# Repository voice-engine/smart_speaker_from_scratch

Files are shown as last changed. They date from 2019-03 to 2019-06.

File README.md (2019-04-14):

Smart Speaker from Scratch
==========================



The project is about to make an affordable, open source smart speaker. It should be able to run Amazon Alexa, Google Assistant, MyCroft, Home Assistant, Mopidy and etc.

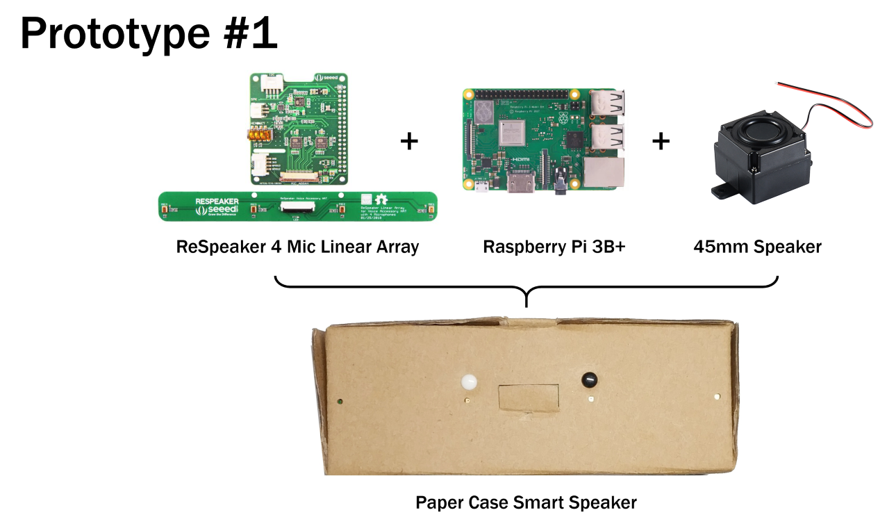
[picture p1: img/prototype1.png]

See the detail at [hardware/prototype-1](/hardware/prototype-1)

### To Do
- Hardware
  - [x] [prototype #1 - Rasbperry Pi + ReSpeaker 4 Mic Linear Array + 45mm Speaker](/hardware/prototype_1)
  - [ ] prototype #2 (on-going)
  - [ ] ...

- Software
  - [ ] AEC (Acoustic Echo Cancellation), See [ec](https://github.com/voice-engine/ec)
  - [ ] ...

- Design
  - [x] prototype #1 - paper case
  - [ ] prototype #2 - wood case, made with [Boxes](https://github.com/florianfesti/boxes)
  - [ ] ...

- Document
  - [x] [Record & Play Audio on Linux](https://github.com/voice-engine/make-a-smart-speaker/issues/5)
  - [ ] Steps to make prototype #1
  - [ ] Introduce how AEC works
  - [ ] ...

### Why

[中文](https://zhuanlan.zhihu.com/p/58690069)

Why should we make an open source smart speaker when there are so many smart speakers on the market? Because these smart speakers are designed from vendors' perspective, not from users' perspective. These smart speakers have two issues:

1. privacy - these speakers are always-listening black boxes which scare lots of people
2. functionality - these speakers can be more powerful, but are limited by the vendors

One best way to eliminate privacy concerns is open source.

Most of smart speakers have very powerful ARM processors. Some even run Android OS just like an Android phone.  The smart speakers only is limited to run only one app, but they have the ability to run thousands of applications.

I want an open source smart speaker which can run Amazon Alexa and Google Assistant at the same time, and also is able to run Home Assistant, Mopidy, Snapcast, Nextcloud and etc.
Maybe you want one too. You can this project on Github or [hackaday.io](https://hackaday.io/project/164221-smart-speaker-from-scratch)

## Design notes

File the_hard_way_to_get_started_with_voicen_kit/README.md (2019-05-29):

The Hard Way To Get Started with VOICEN Kit
===========================================

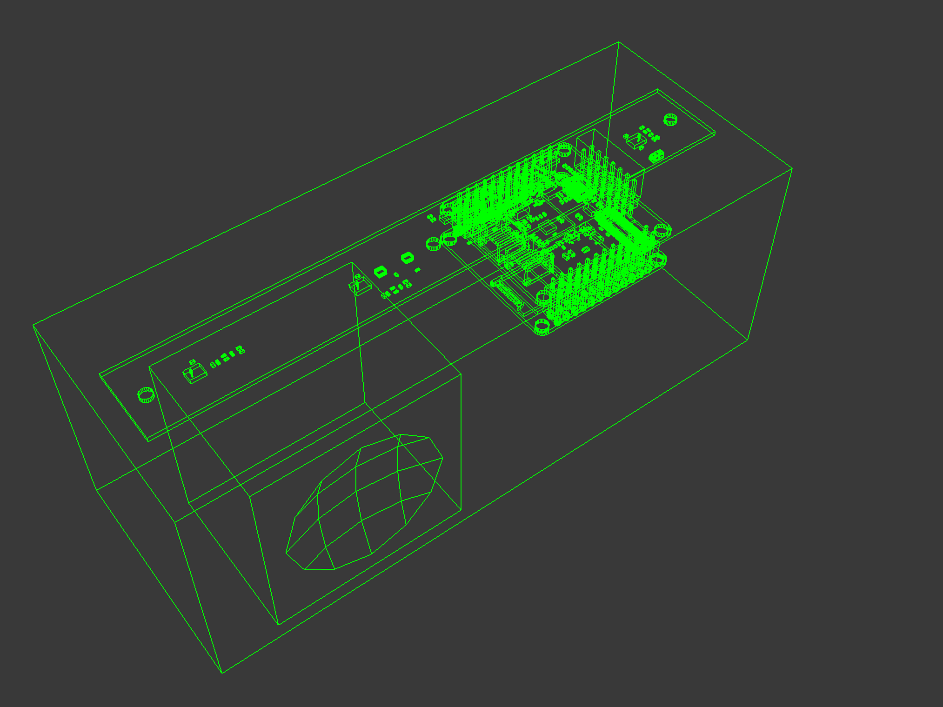
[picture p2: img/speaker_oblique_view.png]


## Hardware
+ VOICEN Kit (Nanopi Neo Air, VOICEN Linear 4 Mic Array, Nano AMP)
+ A SD card

## Setup
1. Download [Armbian for Nanopi Neo Air](https://www.armbian.com/nanopi-neo-air/)
2. Use [Rufus (very tiny but only for windows)](https://rufus.ie/) or [Ether](https://www.balena.io/etcher/) to write Armbian to a SD card.
3. Boot Nanopi Neo Air from the SD card, and then login it via USB virtual serial console. The default user is `root`, its password is `1234`. When you first login it, you will be ask to change the password and create a new user.
4. Use `nmtui` to connect to a WiFi.
5. Install [a customized linux kernel](https://github.com/voice-engine/packages/tree/master/pool/main/l/linux-4.19.25-sunxi) which contains the driver of the VOICEN Linear 4 Mic Array.

## IO Access
[Read/Write IO to control LEDs and to detect touch event ot the touch button.](GPIO)

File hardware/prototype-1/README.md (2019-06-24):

Prototype #1
============

[中文版](zh.md)

To make an open source smart speaker.

### Hardware



The hardware includes:

+ Raspberry Pi 3B
+ A micro SD card
+ ReSpeaker 4 Mic Linear Array
+ 45mm Speaker
+ Laser-Cut Paper Case
+ 2 Nylon Rivets (R3045), the diameter of mounting holes is 3mm (ф3). Screws also work, while rivets are easier to use.

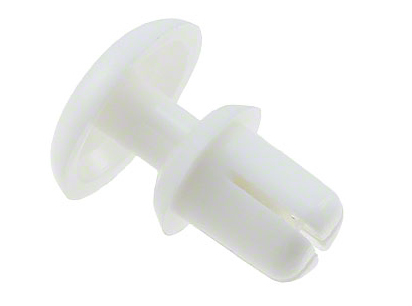
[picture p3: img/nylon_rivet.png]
  

Raspberry Pi and ReSpeaker 4 Mic Linear Array can be found at Seeed Studio, and we get the 45mm speaker and nylon rivets from Alibaba or Taobao.

### Software
+ [Raspbian for ReSpeaker](https://v2.fangcloud.com/share/7395fd138a1cab496fd4792fe5?folder_id=188000207913&lang=en)
+ [Etcher](https://www.balena.io/etcher/) or [Rufus (only for Windows)](https://rufus.akeo.ie/)
+ [VNC Viewer](https://www.realvnc.com/en/connect/download/viewer/chrome/)
+ A SSH client such as MobaXterm or Putty

### Steps
1. Download [a customized Pi image - 2018-08-06-raspbian-for-respeaker.zip](https://v2.fangcloud.com/share/7395fd138a1cab496fd4792fe5?folder_id=188000207913&lang=en)，
   which includes the driver for ReSpeaker 4 Mic Linear Array and some pre-installed packages. Do not use the lite version as we need the desktop enviroment to use a web browser.

2. We can write the image to a micro SD card with [Rufus](https://rufus.akeo.ie/) (very tiny but only for windows) or [Etcher](https://www.balena.io/etcher/).

3. (Optional) Use your computer or your phone to setup a hotspot.

4. Enable SSH and setup WiFi before the first boot of the Pi.

   Add a file named `ssh` to the boot partition of the SD card, which enables SSH, and then create a file named `wpa_supplicant.conf` with the following content (replace `WiFi SSID` and `WiFi Password` with yours):
   
   ```
   country=GB
   ctrl_interface=DIR=/var/run/wpa_supplicant GROUP=netdev
   update_config=1
   network={
	    ssid="WiFi SSID"
	    psk="WiFi Password"
   }
   ```
   
5. Boot your Pi with the SD card，find out its IP address and ssh to it (user:pi, password: raspberry).

   For Windows, use a SSH client such as [MobaXterm](https://mobaxterm.mobatek.net/) or [putty](https://www.chiark.greenend.org.uk/~sgtatham/putty/latest.html). For Linux or macOS, run `ssh` command in a terminal.

6. Enable the VNC server.

   In the SSH terminal, run `sudo raspi-config`, navigate to menus `Interfacing Options >> VNC` and enable the VNC server.

7. Use a VNC viewer to connect to the Pi's remote desktop.

8. Run some test commands:

   ```
   arecord -l                               # list capture devices
   arecord -f dat -d 6 -V mono audio.wav    # record an audio
   aplay -v audio.wav                       # play the audio
   python ~/respeaker/4mic_linear/aec_ns_kws.py   # detect keyword "snowboy", use ctrl + c to exit
   ```

   The output should be:

   ```
   pi@raspberrypi:~ $ arecord -l
   **** List of CAPTURE Hardware Devices ****
   card 1: seeed8micvoicec [seeed-8mic-voicecard], device 0: bcm2835-i2s-ac10x-codec0 ac10x-codec0-0 []
     Subdevices: 1/1
     Subdevice #0: subdevice #0
   pi@raspberrypi:~ $ arecord -f dat -d 6 -V mono audio.wav
   Recording WAVE 'audio.wav' : Signed 16 bit Little Endian, Rate 48000 Hz, Stereo
   ##+                                                | 02%
   pi@raspberrypi:~ $ aplay audio.wav
   Playing WAVE 'audio.wav' : Signed 16 bit Little Endian, Rate 48000 Hz, Stereo
   aplay: xrun:1624: read/write error, state = RUNNING
   pi@raspberrypi:~ $ aplay -v audio.wav
   ...
   pi@raspberrypi:~ $ aplay -v audio.wav
   pi@raspberrypi:~ $ python ~/respeaker/4mic_linear/aec_ns_kws.py
   ['arecord', '-t', 'raw', '-f', 'S16_LE', '-c', '8', '-r', '16000', '-D', 'default', '-q']
   detected 1
   detected 1
   ^Cquit
   ```

9. At the remote desktop window, setup Amazon Alexa Voice Service

   1. the default web browser has some compatible issues, so we need to replace it. open the Chromium web browser and set it as the default web
   2. run `alexa-auth`
   3. open http://127.0.0.1:3000 in the Chromium
   4. click `amazon alexa` and login alexa voice service with your amazon account

10. Run Alexa as a voice assistant

    ```
    cd
    wget https://github.com/voice-engine/smart_speaker_from_scratch/raw/master/hardware/prototype-1/alexa.py
    python alexa.py
    ```

11. Make the python script autorun

    ```
    wget https://github.com/voice-engine/smart_speaker_from_scratch/raw/master/hardware/prototype-1/alexa.service
    sudo cp alexa.service /etc/systemd/system
    sudo systemctl enable alexa.service
    sudo systemctl start alexa.service
    ```

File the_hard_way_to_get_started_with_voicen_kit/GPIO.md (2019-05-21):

GPIO
====

## IO Used By VOICEN Kit

| name | number  | usage |
|---|---|---|
| PA2 | 2 | AMP_PWR_EN |
| PA3 | 3 | AMP_MUTE |
| PC0 | 64 | BLUE LED |
| PC1 | 65 | GREEN LED |
| PC2 | 66 | YELLOW LED |
| PC3 | 67 | RED LED |
| PG11 | 203 | TOUCH BUTTON |

from name to number: 

`n(PC3) = ('C' - 'A') * 32 + 3 = 2 * 32 + 3 = 67`

## 3 ways to access IO
1. sysfs

2. gpiod

   ```
   sudo apt install -y gpiod
   sudo gpioset 0 65=0  # turn on green LED
   sudo gpiomon 0 203   # detect touch event 
   ```

3. direct memory (IO registers)

   ```
   sudo apt install -y sunxi-tools
   sudo sunxi-pio -m PC1=1  # turn on green LED
   ```

   ## Reference
   1. https://github.com/brgl/libgpiod
   2. https://github.com/linux-sunxi/sunxi-tools

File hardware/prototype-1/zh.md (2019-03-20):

原型 #1
=======



### 硬件
所用到的硬件包括:

+ 树莓派 3B 或 3B+
+ ReSpeaker 4 Mic Linear Array
+ 45mm 带音腔的喇叭
+ 激光切割的纸壳 （后面尝试不借助激光切割机 DIY 纸壳）
+ 2个尼龙铆钉 (R3035 或 R3045)，见下图，定位孔是ф3的，用螺丝螺母也可以，但尼龙铆钉使用起来更方便

  

树莓派、ReSpeaker 4 Mic Linear Array、喇叭、铆钉都可以在淘宝上买到，激光切割的纸壳可以在当地的创客空间里制作，很多创客空间都激光切割机、3D打印机。在深圳的话，可以去柴火创客空间，里面有各种各样的工具。

### 设计一个纸壳
激光切割纸壳需要一份CAD设计图，CAD倒是在大学的《机械工程制图》课中学过，已经好几个年头没有用过了，好在设计一个简单纸壳只需要画线、画圆即可，就是数字化尺规作图。
商业的CAD软件都很贵，但对于设计纸壳这个任务，用开源的[LibreCAD](https://librecad.org/)就可以搞定。

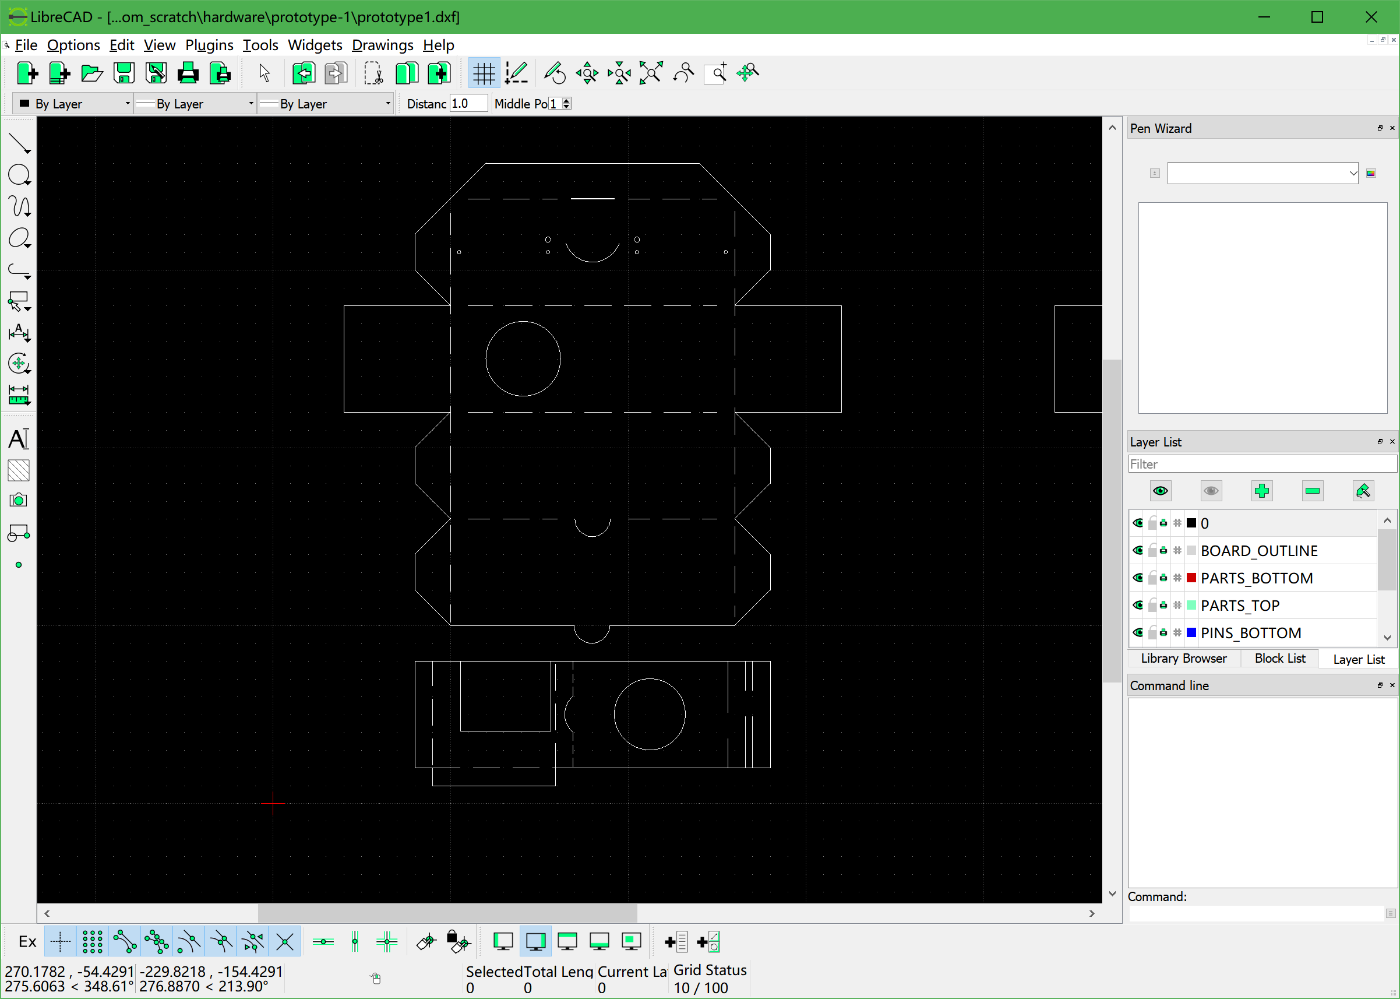
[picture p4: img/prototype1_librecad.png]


如果从来没有接触过CAD制图，上手CAD有一定的门槛，可以Python设计CAD图纸，这里用到[Manfred Moitzi写的一个很好用的Python库ezdxf](https://github.com/mozman/ezdxf)，我们把纸壳的尺寸算清楚，就可以在Python里面画线、画圆了。
用Python设计一些有规律的结构可能比用CAD更快速，比如说设计阵列喇叭孔。

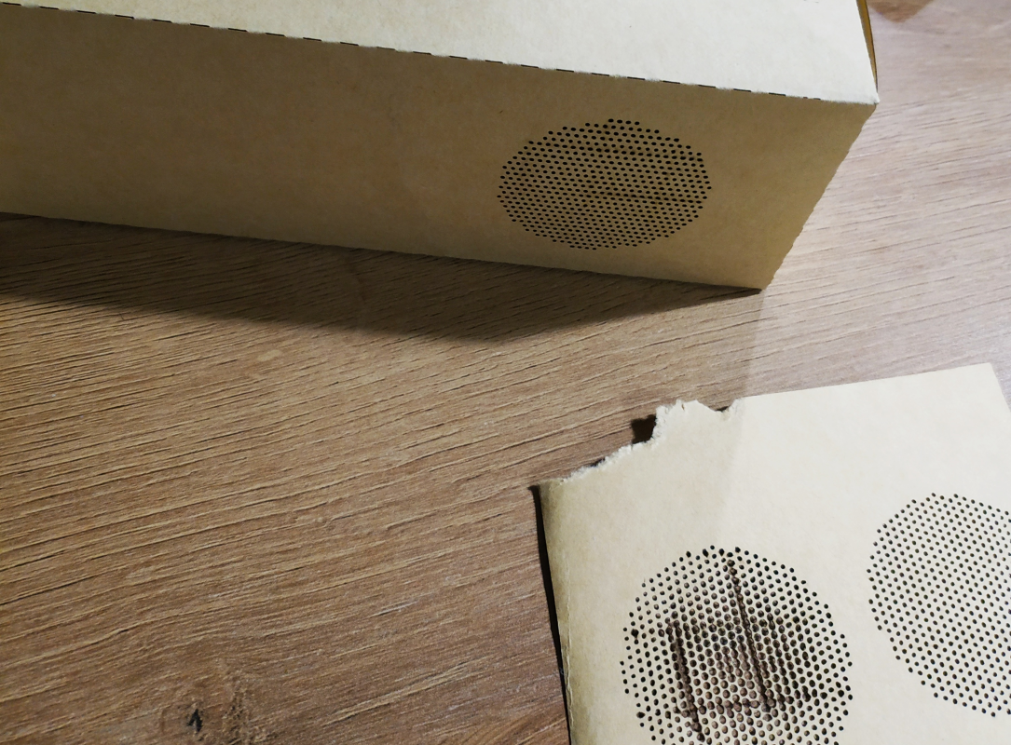
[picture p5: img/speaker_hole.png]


用Python代码设计这样的：

```python
import ezdxf

dwg = ezdxf.new('R2007')
msp = dwg.modelspace()
d = 40.
n = int(40 / 1.5)

delta = d / n

start = (100, 100)

msp.add_circle(start, 20)

for x in range(-n, n):
    for y in range(-n, n):
        if y & 1:
            offset = 0.5
        else:
            offset = 0
        rx = ((x + offset)**2 + y**2)**0.5
        if rx <= (n/2 + 0.1):
            r = 0.35 # (0.25 * delta * (n/2 - rx) / (n/2) + 0.15 * delta)
            msp.add_circle((start[0] + (x + offset) * delta, start[1] + y * delta), r)

dwg.saveas('speaker_hole.dxf')
```
这段代码输出的图形是：

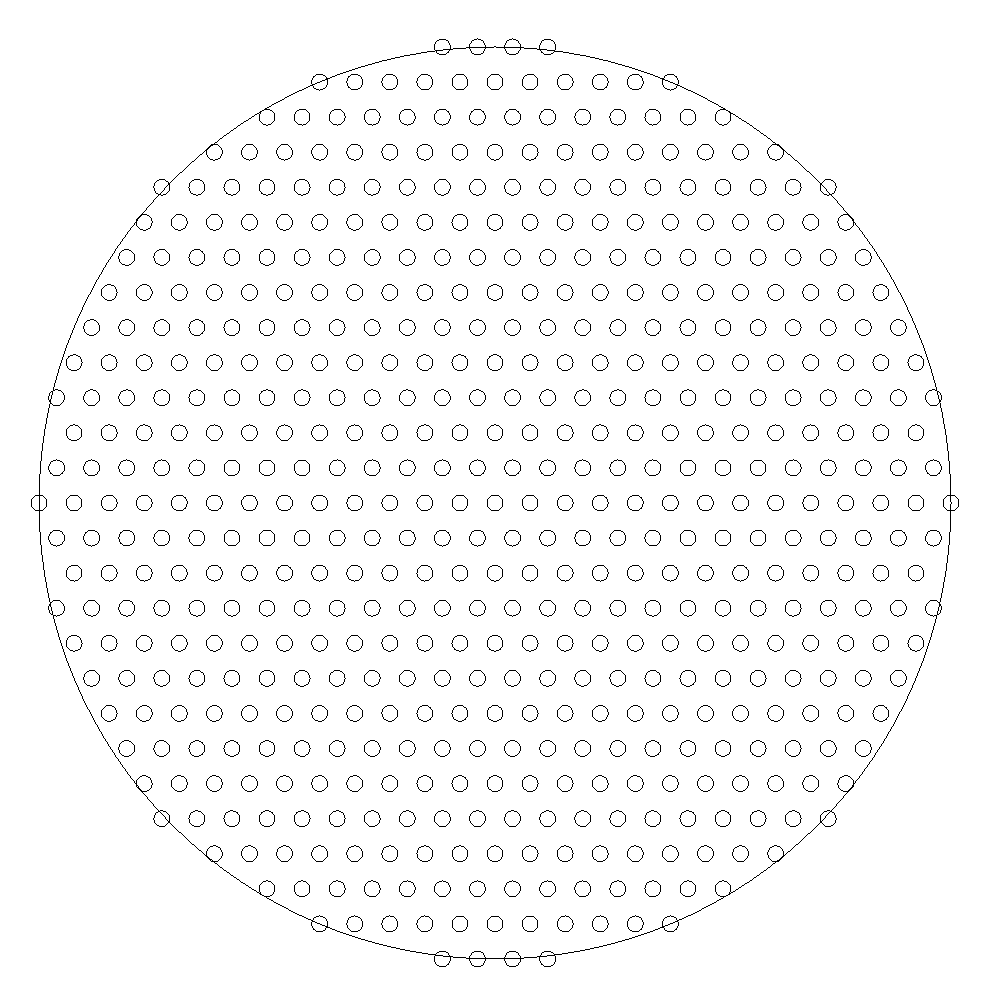
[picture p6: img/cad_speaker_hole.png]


可以将CAD和Python代码结合，进行更复杂的设计。

### 软件
实现语音交互智能音箱的功能，最简单的方法是用各大厂商提供的语音助手服务，Amazon、Google、百度都提供了多种编程语言SDK的支持，百度甚至推出兼容Amazon语音服务的API；像更深层次的折腾，可以尝试MyCroft和wukong-robot；像要离线的使用，可以尝试snips.ai的一套语音交互解决方案。
这里资源的链接都可以在 [voice-engine/make-a-smart-speaker](https://github.com/voice-engine/make-a-smart-speaker) 上找到。

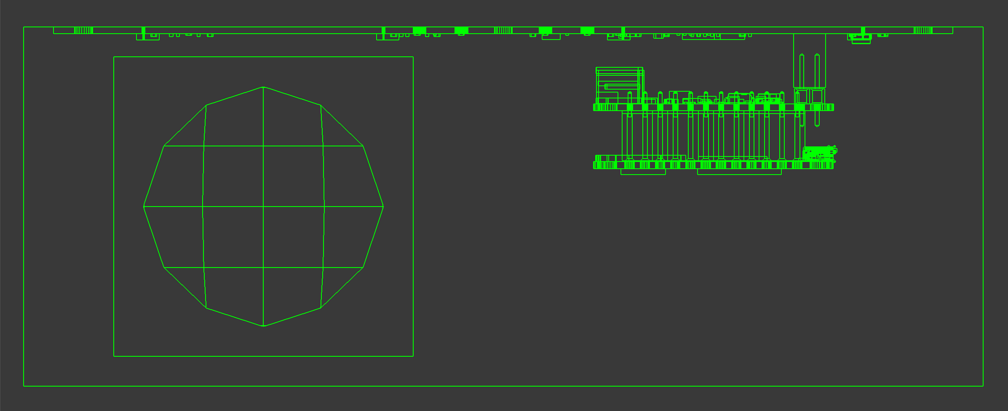
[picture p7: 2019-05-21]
img/speaker_front.png

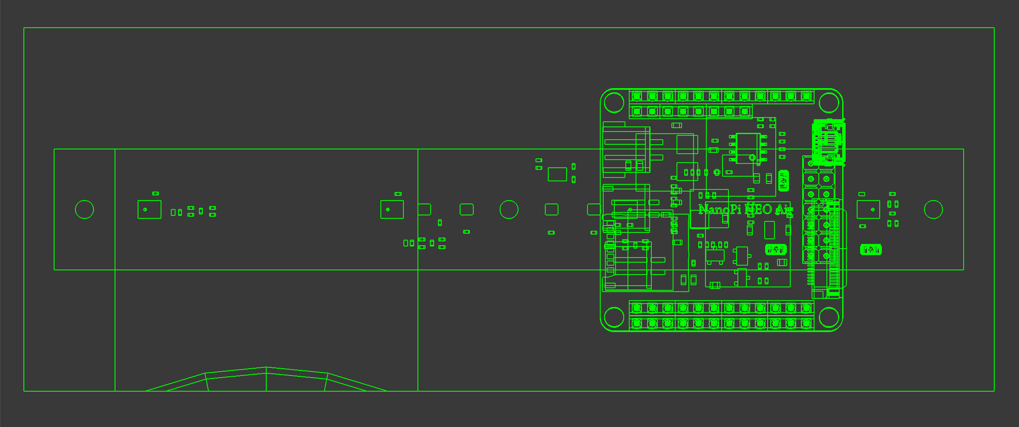
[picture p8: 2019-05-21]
img/speaker_top.png

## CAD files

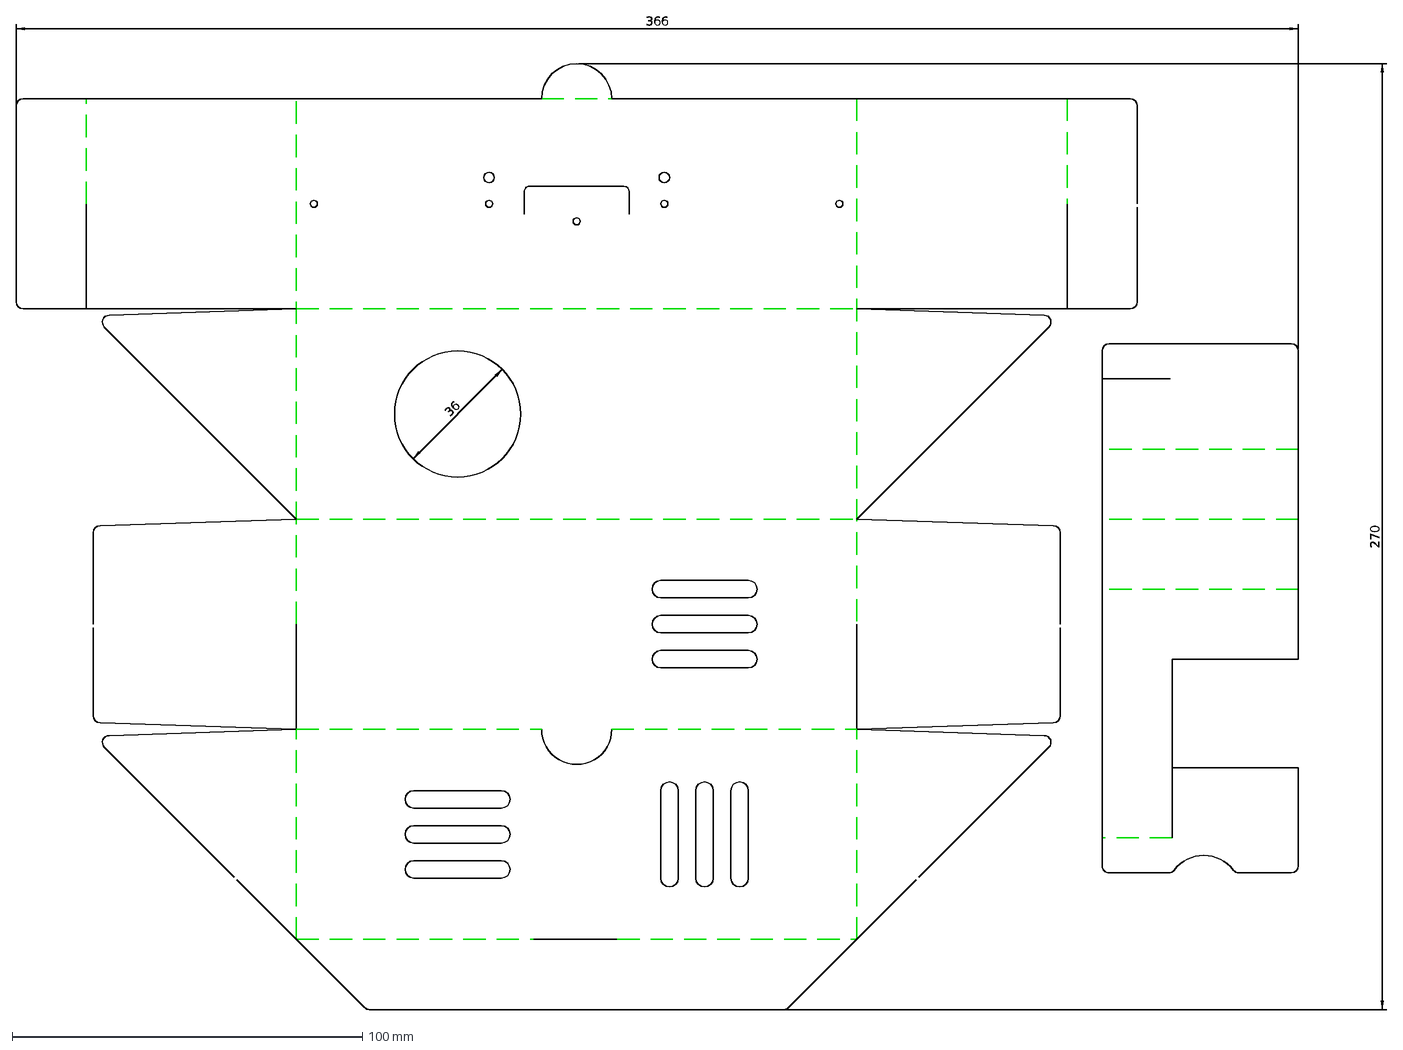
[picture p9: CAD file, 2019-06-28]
hardware/prototype-1/prototype1d.dxf
36
366
270

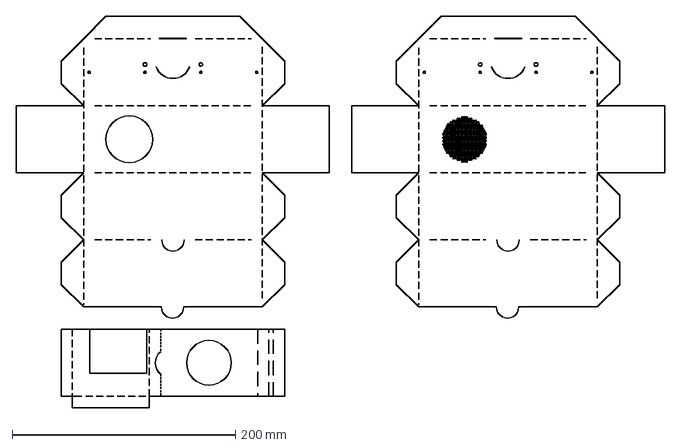
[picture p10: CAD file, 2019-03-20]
hardware/prototype-1/prototype1.dxf
580.0 x 350.0 mm

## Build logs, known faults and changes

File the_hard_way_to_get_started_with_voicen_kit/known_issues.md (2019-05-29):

Known Issues
============

### bluetooth
Try to enable bluetooth on Nanopi Neo Air. After a lot of search, get bluetooth work finally. A few details are:

1. enable UART3 and its CTS & DTS. In /boot/armbianEnv.txt, add something like:

   ```
   param_uart3_rtscts=1
   overlays=uart3
   ```

2. control bluetooth reset pin PG13
3. enable RTC LOSC output

I use a script to test:

```bash
#!/bin/sh

# sudo apt install sunxi-tools devmem2

echo 'Enable 32K RTC LOSC output'
devmem2 0x1f00060 b 1 
echo 'reset bt'
sunxi-pio -m PG13=0 
sleep 1
sunxi-pio -m PG13=1
sleep 1
echo 'attach'
hciattach /dev/ttyS3 bcm43xx 1500000 flow bdaddr 11:22:33:44:55:66
echo 'config'
#hciconfig hci0 up
```

### u-boot can't boot from emmc (U-Boot 2019.04-armbian)
`linux-u-boot-nanopiair-next` in the latest Ambian image can't boot from emmc.
We need to roll back to the old u-boot `linux-u-boot-nanopiair-default`.

To boot from emmc, we need replace u-boot.

```bash
sudo apt install linux-u-boot-nanopiair-default
sudo aptitude hold linux-u-boot-nanopiair-default
sudo armbian-connfig  # then navigate to `System/Install`
```

U-Boot 2019.04-armbian log (not work):
```
U-Boot 2019.04-armbian (May 04 2019 - 09:12:53 +0200) Allwinner Technology

CPU:   Allwinner H3 (SUN8I 1680)
Model: FriendlyARM NanoPi NEO Air
DRAM:  512 MiB
MMC:   mmc@1c0f000: 0, mmc@1c10000: 1
Loading Environment from EXT4... MMC: no card present
In:    serial
Out:   serial
Err:   serial
Net:   No ethernet found.
MMC: no card present
MMC: no card present
starting USB...
No controllers found
Autoboot in 1 seconds, press <Space> to stop
Card did not respond to voltage select!
MMC: no card present
starting USB...
No controllers found
USB is stopped. Please issue 'usb start' first.
starting USB...
No controllers found
No ethernet found.
missing environment variable: pxeuuid
missing environment variable: bootfile
Retrieving file: pxelinux.cfg/00000000
No ethernet found.
missing environment variable: bootfile
Retrieving file: pxelinux.cfg/0000000
No ethernet found.
missing environment variable: bootfile
Retrieving file: pxelinux.cfg/000000
No ethernet found.
missing environment variable: bootfile
Retrieving file: pxelinux.cfg/00000
No ethernet found.
missing environment variable: bootfile
Retrieving file: pxelinux.cfg/0000
No ethernet found.
missing environment variable: bootfile
Retrieving file: pxelinux.cfg/000
No ethernet found.
missing environment variable: bootfile
Retrieving file: pxelinux.cfg/00
No ethernet found.
missing environment variable: bootfile
Retrieving file: pxelinux.cfg/0
No ethernet found.
missing environment variable: bootfile
Retrieving file: pxelinux.cfg/default-arm-sunxi
No ethernet found.
missing environment variable: bootfile
Retrieving file: pxelinux.cfg/default-arm
No ethernet found.
missing environment variable: bootfile
Retrieving file: pxelinux.cfg/default
No ethernet found.
Config file not found
starting USB...
No controllers found
No ethernet found.
No ethernet found.
=> <INTERRUPT>
=>
```

U-Boot 2018.05-armbian
```
U-Boot 2018.05-armbian (Sep 19 2018 - 12:03:31 +0200) Allwinner Technology

CPU:   Allwinner H3 (SUN8I 1680)
Model: FriendlyARM NanoPi NEO Air
DRAM:  512 MiB
MMC:   SUNXI SD/MMC: 0, SUNXI SD/MMC: 1
Loading Environment from EXT4... MMC: no card present
** Bad device mmc 0 **
Failed (-5)
In:    serial
Out:   serial
Err:   serial
Net:   No ethernet found.
MMC: no card present
** Bad device mmc 0 **
MMC: no card present
** Bad device mmc 0 **
starting USB...
No controllers found
Autoboot in 1 seconds, press <Space> to stop
switch to partitions #0, OK
mmc1(part 0) is current device
Scanning mmc 1:1...
Found U-Boot script /boot/boot.scr
3708 bytes read in 8 ms (452.1 KiB/s)
## Executing script at 43100000
U-boot loaded from eMMC or secondary SD
Boot script loaded from mmc
289 bytes read in 4 ms (70.3 KiB/s)
MMC: no card present
** Bad device mmc 0 **
8141541 bytes read in 634 ms (12.2 MiB/s)
7322968 bytes read in 574 ms (12.2 MiB/s)
Found mainline kernel configuration
```

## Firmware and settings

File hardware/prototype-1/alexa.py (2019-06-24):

"""
Record audio from a 6 microphone array, and then search the keyword "snowboy".
After finding the keyword, Direction Of Arrival (DOA) is estimated.

The hardware is respeaker 6 mic array for raspberry pi.
"""

import signal
import time
from voice_engine.source import Source
from voice_engine.ec import EC
from voice_engine.ns import NS
from voice_engine.kws import KWS
from gpiozero import LED
from avs.alexa import Alexa

led = LED(5)
led.off()


def main():
    src = Source(rate=16000, frames_size=320, channels=8)
    ec = EC(channels=src.channels, capture=0, playback=7)
    # ns = NS(rate=src.rate, channels=1)
    kws = KWS(model='alexa')
    alexa = Alexa()

    alexa.state_listener.on_listening = led.on
    alexa.state_listener.on_finished = led.off

    #src.pipeline(ec, ns, kws, alexa)
    src.pipeline(ec, kws, alexa)


    def on_detected(keyword):
        led.on()
        print('detected {}'.format(keyword))
        alexa.listen()

    kws.on_detected = on_detected

    is_quit = []
    def signal_handler(sig, frame):
        is_quit.append(True)
        print('quit')
    signal.signal(signal.SIGINT, signal_handler)

    src.pipeline_start()
    while not is_quit:
        time.sleep(1)

    src.pipeline_stop()
    led.off()

    # wait a second to allow other threads to exit
    time.sleep(1)

if __name__ == '__main__':
    main()

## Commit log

2019-03-20 add prototype 1
    [prototype1.dxf]
2019-06-28 add new design file
    [prototype1d.dxf]
